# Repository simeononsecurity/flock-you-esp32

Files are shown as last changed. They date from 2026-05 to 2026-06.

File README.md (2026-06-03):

# Flock-You: Promiscuous WiFi Edition (`promiscious-dev` branch)

Flock You

**Passive 2.4 GHz promiscuous-mode detector for Flock Safety surveillance infrastructure. Runs standalone or feeds the Flask dashboard over USB for live GPS-tagged wardriving.**

> **Dev note:** This is the `promiscious-dev` branch — adds the
> DeFlockJoplin wildcard-probe tightening and a 31st OUI on top of the
> `promiscious` baseline. See "Further research" below.

---

## Credit

All WiFi promiscuous detection research — the **30-OUI target list**, the **promiscuous-mode strategy**, and the **addr1-receiver detection technique** — is the work of **ØяĐöØцяöЪöяцฐ / @NitekryDPaul**. The firmware here is a mod of his original firmware with added SPIFFS persistence and Flask-dashboard integration. Full research writeup: [`datasets/NitekryDPaul_wifi_ouis.md`](datasets/NitekryDPaul_wifi_ouis.md).

Additional research credit to **Michael / DeFlockJoplin** for the **wildcard-probe-request signature** and the 31st OUI (`82:6b:f2`). Field-tested to 11/12 cameras caught with only 2 false positives in Joplin. Source: [DeflockJoplin/flock-you](https://github.com/DeflockJoplin/flock-you).

---

## What this branch does

Turns a Seeed XIAO ESP32-S3 into a passive WiFi receiver that watches 2.4 GHz management and data frames for Flock Safety MAC OUIs. No AP, no transmit — the radio stays dedicated to sniffing while the device hops channels 1 / 6 / 11 at 350 ms dwell.

Every detection is:

- beeped (piezo on GPIO3) and flashed (onboard LED on GPIO21)
- written to on-device SPIFFS in an atomic CRC-envelope format, surviving power loss
- emitted as one JSON line over USB CDC in the schema `api/flockyou.py` expects, so the Flask dashboard auto-ingests it with GPS temporal matching

The device works standalone (no USB host needed) and plugged in (live dashboard) without any mode switch.

---

## Why promiscuous mode, and why `addr1`

Most WiFi sniffers only check the transmitter address (`addr2`). Flock infrastructure spends most of its duty cycle **asleep** — it wakes briefly in bursts, uploads, then sleeps again. During the silence it may never transmit a single frame in your capture window.

But it may still appear on the air as the **destination** (`addr1`) of probe responses or data frames from nearby APs.

Checking `addr1` in addition to `addr2` picks those silent stations up. It requires two guards to avoid false positives:

- `addr1` is broadcast (`ff:ff:ff:ff:ff:ff`) in beacons and broadcasts — **multicast filter**
- Modern devices use randomised (locally-administered) MACs that can't be fingerprinted by OUI — **randomised-MAC filter** on byte 0 bit 1

Both are applied before the OUI match. This whole approach, including the 30-OUI list, is **@NitekryDPaul's research**.

---

## Further research — the wildcard-probe signature (DeFlockJoplin)

Michael / DeFlockJoplin used the OUI + addr1/addr2/addr3 work above as a starting point and characterised what Flock cameras actually do on the air. His finding:

> The cameras are hopping channels and sending out a wildcard WiFi probe request on every channel. This specific type of request combined with OUI matching has created what seems to be a fairly unique signature.

His drive-test in Joplin caught **11 of 12 cameras** with only **2 false positives**. The 12th camera was doing the same wildcard-probe behaviour but with an OUI (`82:6b:f2`) that wasn't in @NitekryDPaul's original 30 — it's now the 31st entry in our list, credited to him.

The tightened signature that's active on this branch:

1. Frame is 802.11 Management, type=0 subtype=4 (**Probe Request**)
2. SSID Information Element (tag 0) is present with **length 0** (wildcard)
3. `addr2` (transmitter) matches the known-OUI list

When all three hit, we emit `detection_method: wifi_wildcard_probe` — the high-precision class. Non-probe frames from the same OUIs still emit `wifi_oui_addr2`, and the `addr1` receiver-side sleeper-catch still runs independently.

His proof-of-concept firmware (different enough we're not just pulling it in wholesale, but the core idea carried over cleanly): [DeflockJoplin/flock-you](https://github.com/DeflockJoplin/flock-you). The wildcard-probe analysis is his; we ported the detection into this firmware and kept our SPIFFS persistence, Flask JSON emission, and audio/LED feedback on top.

---

## Detection pipeline

```
  [2.4GHz air]
       │
       ▼
  wifiSniffer()                 ← IRAM promiscuous callback (WiFi task)
       │                          fast match only, no Serial / no malloc
       ▼
  alertQueue[32]                ← lock-free ring buffer (ISR-safe mux)
       │
       ▼
  drainAlertQueue()             ← loop() context, per-iteration drain
       │
       ├─► fyAddDetection()           ← always, every hit
       │        │
       │        ▼
       │   fyDet[200]                 ← unique-by-MAC on-device table
       │        │
       │        ▼
       │   autosaveTick()             ← every 60s when dirty
       │        │
       │        ▼
       │   fySaveSession()            ← atomic CRC-envelope write to SPIFFS
       │
       ├─► shouldSuppressDuplicate()  ← 5s per-MAC serial-emit rate limit
       │
       └─► emitDetectionJSON()        ← USB CDC line for Flask
            buzzerBeep() + ledFlash()
```

The split between callback and loop is deliberate: the WiFi task has hard real-time constraints and cannot call `Serial.print` or `malloc` safely. The callback writes only to the lock-free ring buffer; `loop()` does all the heavy work.

---

## OUI target list (@NitekryDPaul research)

All lowercase, colon-separated. 31 Flock Safety infrastructure prefixes:

```
70:c9:4e   3c:91:80   d8:f3:bc   80:30:49   b8:35:32
14:5a:fc   74:4c:a1   08:3a:88   9c:2f:9d   c0:35:32
94:08:53   e4:aa:ea   f4:6a:dd   f8:a2:d6   24:b2:b9
00:f4:8d   d0:39:57   e8:d0:fc   e0:4f:43   b8:1e:a4
70:08:94   58:8e:81   ec:1b:bd   3c:71:bf   58:00:e3
90:35:ea   5c:93:a2   64:6e:69   48:27:ea   a4:cf:12
82:6b:f2   ← contributed by Michael / DeFlockJoplin
```

Pre-compiled into a byte table in `setup()` so the matcher stays entirely in IRAM with no flash-resident lookups during callback execution.

Full dataset and methodology: [`datasets/NitekryDPaul_wifi_ouis.md`](datasets/NitekryDPaul_wifi_ouis.md).

---

## SPIFFS wire format

On-flash layout, atomic and crash-safe:

```
Line 1: {"v":1,"count":N,"bytes":B,"crc":"0xXXXXXXXX"}
Line 2: [{"mac":"...","method":"...","rssi":...,...},...]
```

Save procedure:

1. Compute CRC32 + byte count over the serialised payload
2. Write envelope header + payload to `/session.tmp`
3. Re-read and re-validate `/session.tmp` (CRC check)
4. Remove `/session.json`
5. Atomic rename `/session.tmp` → `/session.json` (copy+delete fallback)

Boot recovery:

1. If `/session.json` validates, promote it to `/prev_session.json`
2. Otherwise try `/session.tmp` (interrupted save)
3. Delete both working files, start with an empty live table
4. `/prev_session.json` stays around for inspection

CRC32 uses the standard `0xEDB88320` polynomial so the same file can be verified on a host with any off-the-shelf CRC tool.

---

## Flask dashboard integration

The firmware emits one JSON line per detection in the same schema the BLE detector uses, so `api/flockyou.py` picks it up with zero changes:

```json
{"event":"detection","detection_method":"wifi_oui_addr2","protocol":"wifi_2_4ghz","mac_address":"aa:bb:cc:dd:ee:ff","oui":"aa:bb:cc","device_name":"","rssi":-62,"channel":6,"frequency":2437,"ssid":""}
```

`detection_method` values:

- `wifi_wildcard_probe` — **Probe Request + wildcard SSID from a known OUI** (the DeFlockJoplin high-precision signature). When this fires, the `addr2` broad alert is suppressed for the same frame to avoid double-counting.
- `wifi_oui_addr2` — transmitter-side OUI match on any non-probe frame
- `wifi_oui_addr1` — **receiver-side OUI match** (the @NitekryDPaul technique)
- `wifi_oui_addr3` — BSSID OUI match (mgmt frames only; disabled by default)
- `wifi_ssid` — SSID keyword match (disabled by default)

### GPS wardriving

GPS is handled Flask-side, since the ESP32 radio is dedicated to sniffing and there's no on-device AP. Two options:

- **USB NMEA puck** plugged into the host running Flask — Flask reads NMEA and timestamps a GPS timeline
- **Flask dashboard open in a phone browser** — browser Geolocation API posts updates to Flask

Flask does a temporal match between detection timestamp and GPS timeline, then exports JSON / CSV / KML for Google Earth.

### Running Flask

```bash
cd api
pip install -r requirements.txt
python flockyou.py
```

Open `http://localhost:5000`, pick your serial port from the UI, detections start showing up live.

---

## Supported Hardware

Five environments are included in `platformio.ini`. Pick the one that matches your board; everything else is automatic.

| Environment | Board | Port type | Speaker / LED | Notes |
|---|---|---|---|---|
| `xiao_esp32s3` | Seeed XIAO ESP32-S3 | `/dev/tty.usbmodem*` | GPIO3 piezo + GPIO21 LED | **Original upstream board** |
| `esp32dev` | Generic ESP32 DevKit | `/dev/tty.usbserial-*` | GPIO25 piezo + GPIO2 LED | Bare dev board |
| `m5atom-echo` | M5Stack Atom Echo | `/dev/tty.usbserial-*` | NeoPixel (G27) + GPIO25 buzzer | Compact with speaker |
| `m5atom-lite` | M5Stack Atom Lite | `/dev/tty.usbserial-*` | NeoPixel (G27), no speaker | Ultra-compact |
| `m5atom-voices3r` | M5Stack Atom VoiceS3R | `/dev/tty.usbmodem*` | ES8311 I²S speaker via M5Unified | ESP32-S3, 8MB PSRAM |

### Pin map — XIAO ESP32-S3 (original)

| Pin | Function |
|-----|---|
| GPIO 3 | Piezo buzzer |
| GPIO 21 | Onboard user LED (active low) |
| GPIO 43 | Serial1 TX mirror (115200 baud) |

### Pin map — Atom VoiceS3R

| Pin | Function |
|-----|---|
| GPIO 41 | User button |
| GPIO 18 | Speaker amp enable (NS4150_CTR, handled by M5Unified) |
| I²S (G45/G0/G48/G4/G3/G17/G11) | ES8311 codec — M5Unified drives this automatically |

Boot sound: **Super Mario Bros. World 1-1 overworld opening riff** (E E _E_ C E G) on VoiceS3R / Atom Echo; first 6 notes of World 1-2 underground on original buzzer boards.

---

## Build and flash

Requires [PlatformIO](https://platformio.org/) (`pip install platformio` or install the VS Code extension).

### Quick start — any board

```bash
# Build for your board (replace <env> with one of the environment names above)
pio run -e <env>

# Build + flash
pio run -e <env> -t upload

# Serial monitor
pio device monitor -e <env>
```

### Board-specific commands

#### Seeed XIAO ESP32-S3 (original upstream board)
```bash
pio run -e xiao_esp32s3 -t upload
pio device monitor -e xiao_esp32s3

# Serial monitor (direct):
screen $(ls /dev/tty.usbmodem* | head -1) 115200
```

#### Generic ESP32 DevKit
```bash
pio run -e esp32dev -t upload
pio device monitor -e esp32dev

# Serial monitor (direct):
screen $(ls /dev/tty.usbserial-* | head -1) 115200
```

#### M5Stack Atom Echo
```bash
pio run -e m5atom-echo -t upload
pio device monitor -e m5atom-echo

# Serial monitor (direct):
screen $(ls /dev/tty.usbserial-* | head -1) 115200
```

#### M5Stack Atom Lite
```bash
pio run -e m5atom-lite -t upload
pio device monitor -e m5atom-lite

# Serial monitor (direct):
screen $(ls /dev/tty.usbserial-* | head -1) 115200
```

#### M5Stack Atom VoiceS3R (ESP32-S3, native USB-CDC)
The VoiceS3R uses native USB — `pio run -t upload` works when the port is free.
If the port is busy (e.g. a serial monitor is open), kill it first:

```bash
# Kill anything holding the CDC port, then flash:
lsof -t /dev/tty.usbmodem* | xargs kill 2>/dev/null; sleep 0.5
pio run -e m5atom-voices3r -t upload

# Or use brew esptool directly (most reliable for ESP32-S3 native USB):
esptool --chip esp32s3 --port /dev/tty.usbmodem101 \
    --before usb-reset --after hard-reset write-flash \
    0x0    .pio/build/m5atom-voices3r/bootloader.bin \
    0x8000 .pio/build/m5atom-voices3r/partitions.bin \
    0xe000 ~/.platformio/packages/framework-arduinoespressif32/tools/partitions/boot_app0.bin \
    0x10000 .pio/build/m5atom-voices3r/firmware.bin

# Serial monitor:
screen /dev/tty.usbmodem101 115200
# (replace 101 with whatever number the port shows — run: ls /dev/tty.usbmodem*)
```

> **Tip:** After flashing the VoiceS3R, unplug and replug the USB cable once to let the firmware re-enumerate the CDC port.

### Testing mode

To alert on **all** WiFi frames (useful for range/hardware testing before deployment), add `-DTESTING_MODE=1` to any env's `build_flags`:

```ini
build_flags =
    ...
    -DTESTING_MODE=1
```

Remove it to return to normal Flock OUI–only detection.

`platformio.ini` and `partitions_4mb.csv` are at the root. The XIAO env uses `partitions.csv` (original upstream layout); all other envs use `partitions_4mb.csv`.

---

## Config cheatsheet (top of `main.cpp`)

| Define | Default | Notes |
|---|---|---|
| `CHANNEL_MODE` | `CHANNEL_MODE_CUSTOM` | `CUSTOM` (1/6/11), `FULL_HOP` (1-11), or `SINGLE` |
| `CHANNEL_DWELL_MS` | 350 | Time on each channel before hop |
| `RSSI_MIN` | -95 | Drop frames weaker than this |
| `ALERT_COOLDOWN_MS` | 5000 | Per-MAC serial-emit rate limit |
| `CHECK_ADDR1` | 1 | The @NitekryDPaul receiver-side technique |
| `CHECK_ADDR3` | 0 | BSSID fallback (mgmt frames only) |
| `ENABLE_SSID_MATCH` | 0 | Substring match against `target_ssid_keywords[]` |
| `PROCESS_MGMT_FRAMES` | 1 | Beacons, probe req/resp, etc. |
| `PROCESS_DATA_FRAMES` | 1 | Data frames (where addr1 catch shines) |
| `MAX_DETECTIONS` | 200 | On-device table cap |
| `AUTOSAVE_INTERVAL_MS` | 60000 | SPIFFS save cadence |
| `LED_PIN` | 21 | Onboard user LED |
| `BUZZER_PIN` | 3 | Piezo |

---

## Standalone vs connected

**Without USB:** device boots, plays the SMB 1-2 intro, starts scanning, stores every unique detection to SPIFFS, flashes the onboard LED on each hit. Plug in later — the prior session is sitting in `/prev_session.json`.

**With USB + Flask running:** same thing, plus every detection streams live to the dashboard as a JSON line. Flask adds GPS (if configured) and deduplicates across MAC, building the wardriving map as you move.

Both modes work simultaneously — the SPIFFS write path doesn't care if a host is listening.

---

## BLE companion firmware

The BLE-only sibling of this firmware lives on the [`main` branch](https://github.com/colonelpanichacks/flock-you/tree/main). It detects Flock and Raven gear via BLE advertisements (OUI prefix, device name, manufacturer ID `0x09C8`, Raven service UUIDs), runs its own WiFi AP with a phone-facing dashboard at `192.168.4.1`, and emits the same Flask JSON schema. Flash both on separate boards for overlapping BLE + WiFi coverage feeding one Flask dashboard.

---

## Acknowledgments

- **ØяĐöØцяöЪöяцฐ (@NitekryDPaul)** — **WiFi promiscuous detection research**: the 30-OUI Flock Safety target list and the addr1-receiver detection technique that are the baseline of this firmware. The code here is a mod of his original work.
- **Michael / DeFlockJoplin** ([DeflockJoplin/flock-you](https://github.com/DeflockJoplin/flock-you), [deflockjoplin.today](https://deflockjoplin.today)) — **wildcard-probe-request signature** + the 31st OUI (`82:6b:f2`). Drive-tested in Joplin to 11/12 cameras caught with only 2 false positives.
- **Will Greenberg** ([@wgreenberg](https://github.com/wgreenberg)) — BLE manufacturer company ID detection (`0x09C8` XUNTONG) sourced from his [flock-you](https://github.com/wgreenberg/flock-you) fork (used by the BLE companion on `main`)
- **[DeFlock](https://deflock.me)** ([FoggedLens/deflock](https://github.com/FoggedLens/deflock)) — crowdsourced ALPR location data and detection methodologies. Datasets included in `datasets/`
- **[GainSec](https://github.com/GainSec)** — Raven BLE service UUID dataset (`raven_configurations.json`) used by the BLE companion

---

## OUI-SPY Firmware Ecosystem

Flock-You is part of the OUI-SPY firmware family:

| Firmware | Description | Board |
|---|---|---|
| **[OUI-SPY Unified](https://github.com/colonelpanichacks/oui-spy-unified-blue)** | Multi-mode BLE + WiFi detector | ESP32-S3 / ESP32-C5 |
| **[OUI-SPY Detector](https://github.com/colonelpanichacks/ouispy-detector)** | Targeted BLE scanner with OUI filtering | ESP32-S3 |
| **[OUI-SPY Foxhunter](https://github.com/colonelpanichacks/ouispy-foxhunter)** | RSSI-based proximity tracker | ESP32-S3 |
| **[Flock You](https://github.com/colonelpanichacks/flock-you)** | Flock Safety / Raven surveillance detection (this project) | ESP32-S3 |
| **[Sky-Spy](https://github.com/colonelpanichacks/Sky-Spy)** | Drone Remote ID detection | ESP32-S3 / ESP32-C5 |
| **[Remote-ID-Spoofer](https://github.com/colonelpanichacks/Remote-ID-Spoofer)** | WiFi Remote ID spoofer & simulator with swarm mode | ESP32-S3 |
| **[OUI-SPY UniPwn](https://github.com/colonelpanichacks/Oui-Spy-UniPwn)** | Unitree robot exploitation system | ESP32-S3 |

---

## Author

**colonelpanichacks**

**Oui-Spy devices available at [colonelpanic.tech](https://colonelpanic.tech)**

---

## Disclaimer

Passive reception of publicly-broadcast 802.11 frames for security research, privacy auditing, and education. The device does not transmit and does not authenticate to any network. Detecting the presence of surveillance hardware in public spaces is legal in most jurisdictions; always comply with local laws regarding wireless reception.

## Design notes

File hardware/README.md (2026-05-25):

# Hardware Directory

This directory contains the 3D printable case design and rendering tools.

## 📁 Contents

```
hardware/
├── openscad/
│   └── flock-you-case.scad       ← Parametric CAD source
├── renders/                       ← Generated product images (create with script)
├── render_models.sh               ← Automated rendering script
├── RENDERING_GUIDE.md             ← Complete rendering documentation
└── README.md                      ← This file
```

---

## 🚀 Quick Start

### To Generate Product Images:

**1. Install OpenSCAD:**
```bash
# macOS
brew install openscad

# Linux
sudo apt-get install openscad
```

**2. Run Rendering Script:**
```bash
cd hardware
./render_models.sh
```

This creates professional renders in `renders/` folder:
- `case-base-iso.png` - Base isometric view
- `case-base-top.png` - Base top view  
- `case-lid-iso.png` - Lid isometric view
- `led-pipe.png` - Light pipe detail
- `assembly-exploded.png` - Full assembly exploded view

**3. Use in Documentation:**
Add the generated images to your README, product pages, and build guides.

---

## 📐 Case Specifications

### Dimensions
- **External:** 70mm × 50mm × 25mm
- **Weight:** ~25g (PLA)
- **Print time:** 2-3 hours

### Features
- ✅ Snap-fit lid (no screws)
- ✅ LED light pipe for GPIO 2
- ✅ USB strain relief
- ✅ Ventilation slots
- ✅ Breadboard mounting posts
- ✅ Car dashboard mounting holes

### Fits
- ESP32 DevKit 30-pin
- 170-point mini breadboard
- KY-006 passive buzzer module
- USB cable with strain relief

---

## 🔧 Customizing the Design

### Edit in OpenSCAD GUI

1. Open `openscad/flock-you-case.scad` in OpenSCAD
2. Modify parameters at top of file:
   ```openscad
   case_length = 70;  // Change dimensions
   case_width = 50;
   case_height = 25;
   ```
3. Press **F5** to preview changes
4. Press **F6** to render final model
5. Export STL: File → Export → Export as STL

### Common Customizations

**Make it bigger/smaller:**
```openscad
case_length = 80;  // 10mm longer
case_width = 55;   // 5mm wider
```

**Add ventilation:**
```openscad
vent_slot_w = 2.0;        // Wider slots
vent_slot_spacing = 3;     // More slots
```

**Different LED position:**
```openscad
// In case_lid() module, change light pipe position
translate([30, 25, -lip_h - 1])  // Move to corner
    cylinder(d=led_pipe_d + tol, h=lid_thick + lip_h + 2);
```

---

## 📦 Printing Instructions

### Recommended Settings
- **Material:** PLA, PETG, or ABS
- **Layer Height:** 0.2mm
- **Infill:** 20%
- **Supports:** None needed
- **Print Time:** 2-3 hours total
- **Cost:** $0.50-0.75 in filament

### Print Order
1. Print **base first** (~2 hours)
2. Test fit with components
3. Print **lid** (~45 min)
4. Print **light pipe** in clear filament (~5 min)

---

## 🎨 Render Examples

Once you run `./render_models.sh`, you'll get:

### Case Base (Isometric View)
Shows internal posts, ventilation slots, USB cutout, and snap-fit tabs.

### Case Lid (Isometric View)  
Shows retaining lip, LED light pipe hole, and snap-fit slots.

### LED Light Pipe
Detail view of the custom light guide for GPIO 2 LED.

### Exploded Assembly
Full assembly view showing how parts fit together.

---

## 📸 For Publishers

If you're publishing this project, generate renders by:

1. Installing OpenSCAD (free, open-source)
2. Running `./render_models.sh`
3. Adding images to:
   - Main README (hero shot)
   - Build guides (step-by-step)
   - Product pages (multiple angles)
   - Social media (eye-catching renders)

**Tip:** Use "Tomorrow Night" color scheme for professional dark backgrounds.

---

## 🎓 Learning Resources

- **Full guide:** See `RENDERING_GUIDE.md` for complete documentation
- **OpenSCAD manual:** [openscad.org/documentation](https://openscad.org/documentation.html)
- **Video tutorials:** Search "OpenSCAD rendering" on YouTube

---

## ✅ Checklist for Publication

- [ ] OpenSCAD installed
- [ ] Renders generated (`./render_models.sh`)
- [ ] STL files exported (if distributing printable files)
- [ ] Images added to main README
- [ ] Case design credited in documentation
- [ ] Print settings verified with test print

---

## 🤝 Contributing

Designed a better case? Created a variant?

1. Fork the repository
2. Modify `flock-you-case.scad`
3. Generate renders of your design
4. Submit pull request with photos

**License:** Creative Commons CC-BY-SA 4.0  
Share and remix freely, credit original designers.

---

## 📝 Notes

**Render script not working?**
- Check that OpenSCAD is installed: `openscad --version`
- Verify script is executable: `chmod +x render_models.sh`
- See `RENDERING_GUIDE.md` for troubleshooting

**Need different angles?**
- Edit camera parameters in `render_models.sh`
- Or use OpenSCAD GUI: View → Cameras → Choose angle
- See rendering guide for camera parameter details

**Want to sell printed cases?**
That's explicitly allowed under CC-BY-SA 4.0!
- Print and sell commercially
- Must credit original design
- Share derivative designs under same license

---

## 🎉 Ready to Build!

You now have:
- ✅ Parametric CAD source (customizable)
- ✅ Rendering tools (professional images)
- ✅ Complete documentation
- ✅ Print-ready design

**Next step:** Install OpenSCAD, run `./render_models.sh`, and generate your product images!

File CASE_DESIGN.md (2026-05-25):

# 3D Printable Case Design - Flock-You ESP32

## 📐 Case Specifications

This case is designed to hold a complete Flock-You detector with breadboard assembly.

### Fits These Components
- ESP32 DevKit 30-pin (48mm × 28mm × 12mm)
- 170-point mini breadboard (45mm × 35mm × 9mm)
- KY-006 passive buzzer module (19mm × 15mm)
- USB Micro cable (with strain relief)
- Jumper wires

### Dimensions
- **External:** 70mm (L) × 50mm (W) × 25mm (H)
- **Wall thickness:** 2mm
- **Weight:** ~25g (PLA)
- **Print time:** 2-3 hours (0.2mm layer height)

### Features
✅ Snap-fit lid (no screws needed)  
✅ USB cable strain relief  
✅ LED light pipe for GPIO 2  
✅ Ventilation slots  
✅ Breadboard mounting posts  
✅ Car dashboard mounting holes  
✅ Optional velcro mounting surface  
✅ Compact,

 pocketable design  

---

## 🖨️ Printing Instructions

### Recommended Settings

| Setting | Value | Notes |
|---|---|---|
| **Material** | PLA, PETG, or ABS | PLA easiest, PETG for heat resistance |
| **Layer Height** | 0.2mm | 0.15mm for smoother finish |
| **Infill** | 20% | Gyroid or Grid pattern |
| **Wall Line Count** | 3 | Strong walls |
| **Top/Bottom Layers** | 4 | Solid top/bottom |
| **Print Speed** | 50mm/s | Slower for better quality |
| **Support** | No | Designed to print without |
| **Bed Adhesion** | Brim | Helps with warping |
| **Rafts** | No | Not needed |

### Color Recommendations
- **Base:** Black or gray (looks professional)
- **Lid:** Clear/translucent (see LED through light pipe)
- **Accent parts:** Red or yellow (for button/indicator)

### Print Time & Cost
- **Base:** 1.5-2 hours, ~15g filament ($0.30-0.50)
- **Lid:** 30-45 minutes, ~8g filament ($0.15-0.25)
- **Total:** 2-3 hours, ~25g filament ($0.50-0.75)

---

## 📦 Files Included

All STL files are in `/firmware/hardware/stl/` folder:

1. **flock-you-case-base.stl** - Main enclosure bottom
2. **flock-you-case-lid.stl** - Snap-on top cover
3. **flock-you-led-pipe.stl** - Light guide for onboard LED
4. **flock-you-mount-bracket.stl** - Optional car mount (separate)

### Optional Parts
5. **spacer-3mm.stl** - Raises lid if components too tall
6. **usb-adapter-90deg.stl** - Right-angle USB adapter holder

---

## 🔧 Assembly Instructions

### What You Need
- Printed case base & lid
- LED light pipe (printed clear)  
- Assembled ESP32 + breadboard + buzzer
- (Optional) 2× M3×8mm screws for mounting bracket

### Step-by-Step

**Step 1: Install LED Light Pipe**
1. Locate LED light pipe hole in case lid (small circular hole)
2. Insert printed light pipe from inside
3. Push gently until it clicks flush
4. The pipe should protrude slightly inside to touch GPIO 2 LED

**Step 2: Mount Breadboard**
1. Identify 4 mounting posts inside case base
2. Peel adhesive backing off breadboard (if present)
3. Align breadboard over mounting posts
4. Press down firmly to seat breadboard
5. (Optional) Add small piece of double-sided tape for extra grip

**Step 3: Route USB Cable**
1. Thread USB cable through strain relief channel
2. Plug into ESP32
3. Cable should exit at back of case cleanly
4. Gentle pressure on strain relief locks cable in place

**Step 4: Close the Lid**
1. Align lid tabs with case base slots (4 corners)
2. Gently push down lid starting from one end
3. Work around perimeter, pressing each tab
4. Lid should "snap" into place securely
5. To open: Insert fingernail in slot at front, flex and lift

**Step 5: Test Fit**
1. Plug in USB to power on
2. LED should be visible through light pipe
3. Buzzer sound should be clear (not muffled)
4. All buttons accessible (if added)

### Common Issues & Fixes

**Lid won't snap:**
- Tabs too thick - sand them down slightly
- Posts interfering - trim with flush cutters
- Print elephants foot - scale lid X/Y by 101%

**Buzzer sounds muffled:**
- Add ventilation slots (see OpenSCAD mod below)
- Orient buzzer facing down toward slots
- Add acoustic port (drill 8mm hole)

**USB cable loose:**
- Add small zip tie through strain relief
- Print thicker strain relief variant
- Use hot glue (remove

able) as temporary fix

---

## 🖥️ OpenSCAD Source Code

The case is parametric - easily modify dimensions!

### Download & Edit

1. Install [OpenSCAD](https://openscad.org/) (free, open-source)
2. Open `/firmware/hardware/openscad/flock-you-case.scad`
3. Modify parameters at top of file
4. Press F5 to preview, F6 to render
5. Export STL: File → Export → Export as STL

### Quick Customization Parameters

```openscad
// === USER PARAMETERS ===

// Case dimensions (mm)
case_length = 70;
case_width = 50;
case_height = 25;
wall_thickness = 2;

// Component fitment
esp32_length = 48;
esp32_width = 28;
breadboard_length = 45;
breadboard_width = 35;

// Features
led_pipe_diameter = 3;  // Light pipe for GPIO 2 LED
usb_cutout_width = 12;
usb_strain_relief = true;
ventilation_slots = true;
mounting_holes = true;

// Tolerances (increase if too tight)
snap_fit_tolerance = 0.3;
component_clearance = 1.0;
```

### Full OpenSCAD Code

Save as `flock-you-case.scad`:

```openscad
// ============================================
// Flock-You ESP32 Case - Parametric Design
// ============================================
// Licensed under Creative Commons CC-BY-SA 4.0
// Designed for ESP32 DevKit + Breadboard

// === PARAMETERS ===

// Case dimensions
case_length = 70;
case_width = 50;
case_height = 25;
wall = 2;
corner_r = 3;

// Component dimensions
esp32_l = 48;
esp32_w = 28;
esp32_h = 12;
breadboard_l = 45;
breadboard_w = 35;
breadboard_h = 9;

// Features
led_pipe_d = 3;
led_pipe_h = 8;
usb_w = 12;
usb_h = 8;
vent_slot_w = 1.5;
vent_slot_spacing = 4;

// Tolerances
tol = 0.3;
clearance = 1.0;

// === MODULES ===

module case_base() {
    difference() {
        // Main body
        minkowski() {
            cube([case_length - 2*corner_r, 
                  case_width - 2*corner_r, 
                  case_height/2]);
            cylinder(r=corner_r, h=case_height/2, $fn=32);
        }
        
        // Hollow interior
        translate([wall, wall, wall])
            cube([case_length - 2*wall, 
                  case_width - 2*wall,
                  case_height]);
        
        // USB cutout (back)
        translate([case_length - wall - 5, 
                   (case_width - usb_w)/2, 
                   wall + 2])
            cube([10, usb_w, usb_h]);
        
        // USB strain relief channel
        translate([case_length - 15, 
                   (case_width - usb_w + 2)/2, 
                   wall])
            cube([15, usb_w - 2, 3]);
        
        // Ventilation slots (bottom)
        for (i = [0:5]) {
            translate([10 + i * vent_slot_spacing, 
                       5, 
                       -1])
                cube([vent_slot_w, case_width - 10, wall + 2]);
        }
        
        // Mounting holes (corners, optional)
        for (x = [5, case_length - 5])
            for (y = [5, case_width - 5])
                translate([x, y, -1])
                    cylinder(d=3.2, h=wall + 2, $fn=16);
    }
    
    // Breadboard mounting posts
    post_h = 3;
    post_d = 3;
    posts_offset_x = (case_length - breadboard_l) / 2;
    posts_offset_y = (case_width - breadboard_w) / 2;
    
    for (x = [posts_offset_x, posts_offset_x + breadboard_l - post_d])
        for (y = [posts_offset_y, posts_offset_y + breadboard_w - post_d])
            translate([x, y, wall])
                cylinder(d=post_d, h=post_h, $fn=16);
    
    // Snap-fit tabs (lid retention)
    tab_w = 4;
    tab_h = 2;
    tab_d = 1.5;
    
    for (x = [10, case_length - 10 - tab_w])
        for (y = [0, case_width - tab_d]) {
            translate([x, y, case_height - tab_h])
                cube([tab_w, tab_d, tab_h]);
        }
}

module case_lid() {
    lid_thick = 2;
    lip_h = 3;
    lip_inset = wall - tol;
    
    difference() {
        union() {
            // Top surface
            minkowski() {
                cube([case_length - 2*corner_r, 
                      case_width - 2*corner_r, 
                      lid_thick/2]);
                cylinder(r=corner_r, h=lid_thick/2, $fn=32);
            }
            
            // Retaining lip
            translate([lip_inset, lip_inset, -lip_h])
                cube([case_length - 2*lip_inset, 
                      case_width - 2*lip_inset,
                      lip_h]);
        }
        
        // LED light pipe hole
        translate([case_length/2, case_width/2, -lip_h - 1])
            cylinder(d=led_pipe_d + tol, h=lid_thick + lip_h + 2, $fn=16);
        
        // Snap-fit tab slots
        tab_w = 4 + 2*tol;
        tab_h = 2 + tol;
        tab_d = 1.5 + tol;
        
        for (x = [10 - tol, case_length - 10 - tab_w + tol])
            for (y = [-1, case_width - tab_d + 1]) {
                translate([x, y, -lip_h - 1])
                    cube([tab_w, tab_d, lip_h + tab_h + 1]);
            }
        
        // Label recess (optional)
        translate([case_length/2 - 20, case_width/2 - 5, lid_thick - 0.5])
            linear_extrude(0.6)
                text("FLOCK-YOU", size=4, halign="center", font="Liberation Sans:style=Bold");
    }
}

module led_light_pipe() {
    // Clear filament light guide
    pipe_l = led_pipe_h;
    pipe_d = led_pipe_d - 0.2;  // Snug fit
    
    cylinder(d1=pipe_d, d2=pipe_d - 0.5, h=pipe_l, $fn=32);
    
    // Retention ridge
    translate([0, 0, pipe_l - 1])
        cylinder(d=pipe_d + 0.5, h=0.5, $fn=32);
}

module mounting_bracket() {
    // Car dashboard / velcro mount
    bracket_l = case_length + 10;
    bracket_w = 30;
    bracket_thick = 3;
    
    difference() {
        // Base plate
        minkowski() {
            cube([bracket_l - 2*corner_r, 
                  bracket_w - 2*corner_r, 
                  bracket_thick/2]);
           cylinder(r=corner_r, h=bracket_thick/2, $fn=32);
        }
        
        // Screw holes for case attachment
        for (x = [5, case_length + 5])
            for (y = [bracket_w/2])
                translate([x, y, -1])
                    cylinder(d=3.2, h=bracket_thick + 2, $fn=16);
        
        // Velcro adhesive area (smooth)
        translate([bracket_l/2 - 25, 5, bracket_thick - 0.5])
            cube([50, bracket_w - 10, 1]);
    }
}

// === RENDER SELECTION ===

// Uncomment the part you want to generate:

case_base();

//translate([0, case_width + 10, 0])  // Offset for printing both
//    case_lid();

//translate([case_length/2, case_width/2, 0])
//    led_light_pipe();

//translate([0, case_width + 40, 0])
//    mounting_bracket();
```

---

## 🎨 Customization Ideas

### 1. Add Text Label
```openscad
linear_extrude(0.6)
    text("DEFLOCK", size=6, font="Arial:style=Bold");
```

### 2. Bigger Ventilation
```openscad
// Replace ventilation_slots section with:
for (i = [0:8]) {
    translate([8 + i * 3, 3, -1])
        cube([2, case_width - 6, wall + 2]);
}
```

### 3. Battery Compartment
```openscad
// Add to case_base():
translate([5, 5, wall])
    cube([20, case_width - 10, 15]);  // 18650 holder space
```

### 4. External Antenna Port
```openscad
// For ESP32-WROOM-32U with U.FL connector:
translate([10, case_width - wall - 1, case_height/2])
    rotate([90, 0, 0])
        cylinder(d=6.5, h=wall + 2, $fn=16);  // SMA bulkhead mount
```

### 5. Lanyard Hole
```openscad
translate([case_length - 5, case_width/2, case_height - 5])
    rotate([0, 90, 0])
        cylinder(d=4, h=wall + 2, $fn=16);
```

---

## 📏 Dimensions Reference

### ESP32 DevKit 30-pin Footprint
```
            48mm
    ┌──────────────────┐
    │    ESP32-WROOM   │
    │                  │ 28mm
    │  USB ████████    │
    └──────────────────┘
    
Pin spacing: 2.54mm (0.1")
Board thickness: 1.6mm
Height with components: ~12mm
```

### KY-006 Buzzer Module
```
       19mm
    ┌────────┐
    │  )))   │ 15mm
    │  )))   │
    └─●─●─●──┘
     S + GND
```

### 170-Point Breadboard
```
         45mm
    ┌──────────────┐
    │ ● ● ● ● ● ●  │
    │ ● ● ● ● ● ●  │ 35mm
    │ ● ● ● ● ● ●  │
    └──────────────┘
    
Mounting holes: 41mm × 31mm spacing
```

---

## 🛠️ Post-Processing

### Smoothing & Finishing

**Method 1: Sanding**
1. Wet-sand with 220 grit → 400 grit → 800 grit
2. Wipe clean with damp cloth
3. Optional: Clear coat spray (matte or gloss)

**Method 2: Vapor Smoothing** (ABS only)
1. Suspend print in sealed container
2. Add small amount of acetone to bottom
3. Leave 30 seconds - 2 minutes
4. Remove and let cure 24 hours
5. ⚠️ Ventilate well, acetone fumes hazardous

**Method 3: Filler + Paint**
1. Apply spray filler primer
2. Sand smooth with 400 grit
3. Spray paint desired color
4. Clear coat for protection

### Light Pipe Optimization

For best LED visibility:
1. Print light pipe in **clear or natural PLA**
2. Sand inside surface lightly (diffuses light)
3. Polish outside with progressively finer sandpaper (up to 3000 grit)
4. Optional: Apply clear epoxy resin for glass-like finish

---

## 📖 Design Philosophy

### Why This Design?

**✅ Printable Without Supports**
- All overhangs < 45°
- No bridging over large gaps
- Snap-fits eliminate screws

**✅ Accessible Components**
- Easy to open for firmware updates
- USB port accessible
- LED visible
- Buzzer unobstructed

**✅ Vehicular Use**
- Mounting options for dashboard
- Strain relief prevents cable damage
- Compact size fits cupholder
- Ventilated for heat dissipation

**✅ Beginner-Friendly**
- Simple two-part design
- No complex assembly
- Tolerances forgiving (±0.3mm works)
- Remixable OpenSCAD source

---

## 🔄 Remix & Share

### License: Creative Commons CC-BY-SA 4.0

**You are free to:**
- ✅ Share — copy and redistribute
- ✅ Adapt — remix, transform, build upon
- ✅ Commercial use - sell printed cases

**Under these terms:**
- 📝 Attribution — Credit original designer
- 🔄 ShareAlike — Same license on derivatives
- 🚫 No additional restrictions

### Share Your Remix!
- Upload to Thingiverse, Printables, or Thangs
- Tag with #flockyou #esp32 #surveillance
- Link back to original design
- Post photos of your build!

---

## 🎓 Learning Resources

### New to 3D Printing?
- **Basics:** [All3DP Beginner's Guide](https://all3dp.com/)
- **Software:** [PrusaSlicer Tutorial](https://help.prusa3d.com/)
- **Troubleshooting:** [Simplify3D Print Quality Guide](https://www.simplify3d.com/support/print-quality-troubleshooting/)

### OpenSCAD Resources
- **Official Docs:** [openscad.org/documentation](https://openscad.org/documentation.html)
- **Tutorial:** [OpenSCAD for Beginners](https://en.wikibooks.org/wiki/OpenSCAD_User_Manual)
- **Gallery:** Thousands of parametric designs to learn from

### Want to Modify?
1. Start with provided parameters (easy)
2. Add simple features (holes, text)
3. Learn modules (reusable components)
4. Advanced: Create fully parametric designs

---

## ✅ Print Checklist

- [ ] STL files downloaded
- [ ] Slicer configured (settings above)
- [ ] Printer bed leveled
- [ ] Filament loaded (20g+ needed)
- [ ] Print started (base first)
- [ ] Base printed successfully (~2 hours)
- [ ] Lid printed (~45 minutes)
- [ ] Light pipe printed (clear filament, ~5 min)
- [ ] Parts cleaned (remove brim/supports if any)
- [ ] Test fit (lid snaps onto base)
- [ ] Ready to assemble!

---

## 🎉 You're Done!

You now have a **professional-looking enclosure** for your Flock-You detector!

**Case cost:** $0.50-0.75 in filament  
**Print time:** 2-3 hours  
**Assembly time:** 5 minutes  
**Result:** Clean, portable, car-ready detector  

**Optional add-ons:**
- Vinyl sticker with warning/branding
- Velcro strips for quick mounting
- Carabiner clip for lanyard attachment
- External antenna mod for extended range

Happy printing! 🖨️

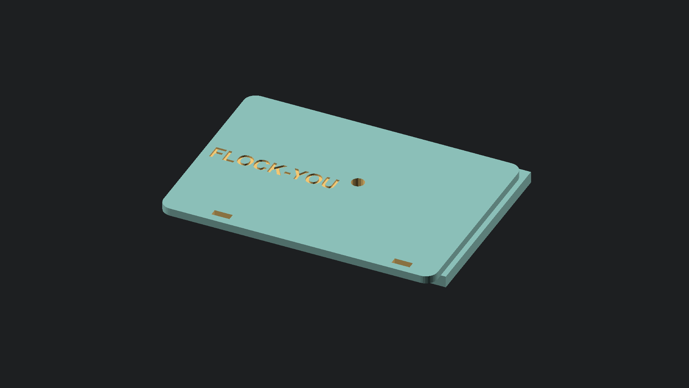
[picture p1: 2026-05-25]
hardware/renders/case-lid-iso.png

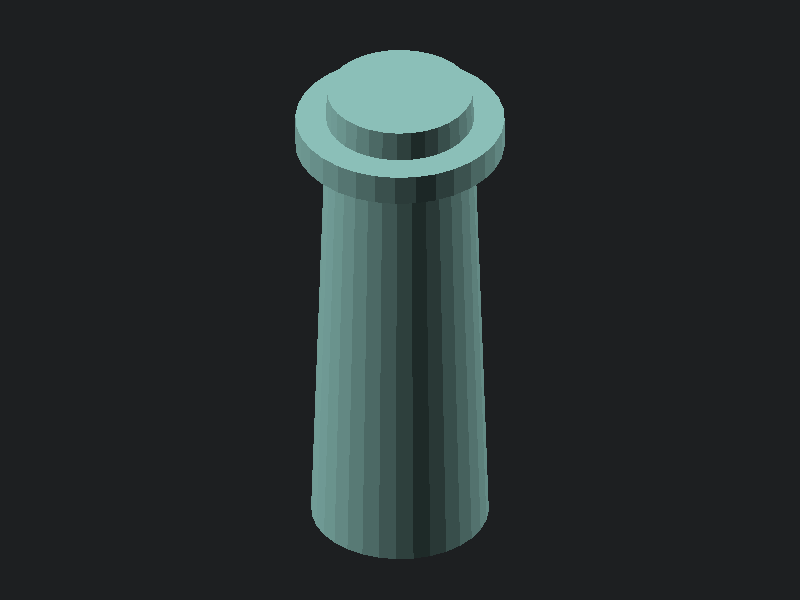
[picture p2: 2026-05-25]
hardware/renders/led-pipe.png

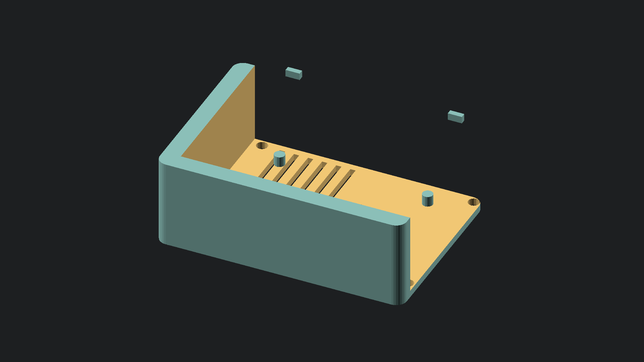
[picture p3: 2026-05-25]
hardware/renders/case-base-iso.png

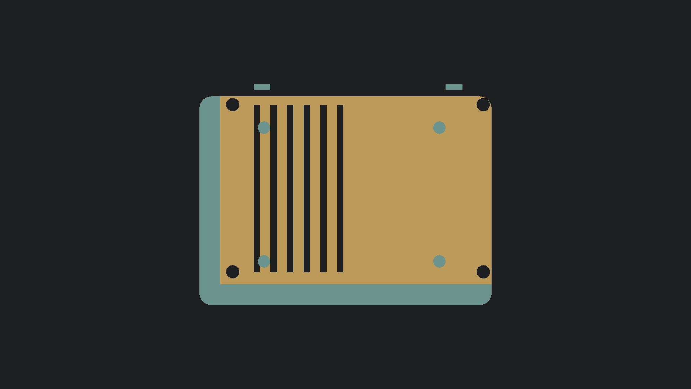
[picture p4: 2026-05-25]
hardware/renders/case-base-top.png

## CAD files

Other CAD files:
hardware/openscad/flock-you-case.scad

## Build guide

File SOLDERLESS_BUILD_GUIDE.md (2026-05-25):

# Solderless Build Guide - Flock-You ESP32

## 🎯 Goal: Build Without Soldering

This guide shows you how to assemble a Flock-You detector using **zero soldering** - perfect for beginners or quick prototypes.

---

## 🛒 Shopping List (Solderless Components)

### Option 1: Breadboard Build ($8-10)
| Item | Quantity | Price | Where to Buy |
|---|---|---|---|
| ESP32 DevKit (30-pin) | 1 | $5-6 | Amazon, AliExpress |
| 400-point Breadboard | 1 | $2 | Amazon, AliExpress |
| Passive Piezo Buzzer Module | 1 | $1-2 | Amazon, AliExpress |
| Male-to-Male Jumper Wires | 3 | <$1 | Amazon, AliExpress |
| USB Micro Cable | 1 | $1 | Amazon, local stores |

**Total: $9-11**

### Option 2: Grove System Build ($12-15)
| Item | Quantity | Price | Where to Buy |
|---|---|---|---|
| ESP32 DevKit with Grove Base | 1 | $8-10 | Seeed Studio, Amazon |
| Grove Buzzer Module | 1 | $3-4 | Seeed Studio, Amazon |
| Grove Cable (4-pin) | 1 | $1 | Usually included |
| USB Micro Cable | 1 | $1 | Amazon, local stores |

**Total: $13-16**

### Option 3: Qwiic/STEMMA System Build ($15-18)
| Item | Quantity | Price | Where to Buy |
|---|---|---|---|
| ESP32 DevKit (any) | 1 | $5-6 | Amazon, AliExpress |
| Qwiic/STEMMA Buzzer Breakout | 1 | $6-8 | Adafruit, SparkFun |
| Qwiic/STEMMA Cable | 1 | $1-2 | Adafruit, SparkFun |
| Female-to-Female Jumpers | 3 | $1 | Amazon, AliExpress |
| USB Micro Cable | 1 | $1 | Amazon, local stores |

**Total: $14-19**

---

## 🔧 Option 1: Breadboard Build (Recommended)

### Parts You Need

**1. ESP32 DevKit Board**
- Any 30-pin ESP32-WROOM-32 DevKit
- Make sure it has 15 pins on each side
- $5-6 on Amazon/AliExpress

**2. Passive Piezo Buzzer Module**
Look for modules with **3 pins** (VCC, GND, I/O):
- **KY-006** Passive Buzzer Module ~$1-2
- **XY-T** Passive Buzzer Module ~$1-2
- Any "passive piezo buzzer module" with 3 pins

**Important:** Get "passive" not "active"! 
- ✅ **Passive** = can play different tones (what we need)
- ❌ **Active** = only one tone (won't work)

**3. Breadboard & Jumpers**
- 400-point breadboard (standard half-size)
- 3× male-to-male jumper wires
- Any color works, but red/black/yellow helps

### Assembly Steps

**Step 1: Insert ESP32 into Breadboard**
```
   Breadboard Layout (top view)
   ═══════════════════════════════
   ┌─────────────────────────────┐
   │  1  2  3  4  5 ... 15       │
   │  ●  ●  ●  ●  ●  ...  ●      │ ← ESP32 Left Side
   │                             │
   │  ●  ●  ●  ●  ●  ...  ●      │ ← ESP32 Right Side
   │  1  2  3  4  5 ... 15       │
   └─────────────────────────────┘
```

1. Straddle the ESP32 across the center gap
2. Push down gently but firmly
3. All 30 pins should be inserted

**Step 2: Connect Buzzer Module**

Buzzer modules typically have 3 pins:
- **S** or **I/O** = Signal pin
- **VCC** or **+** = Power (3.3V or 5V)
- **GND** or **-** = Ground

**Wiring:**
```
ESP32 DevKit          Buzzer Module
━━━━━━━━━━━━━━━━━━━━━━━━━━━━━━━━━━━━
    GPIO 25  ────────► S (Signal/I/O)
    
    3V3      ────────► VCC (+) or (leave unconnected*)
    
    GND      ────────► GND (-)
```

**Important Note:** Most passive buzzer modules are "self-powered" from the signal pin and don't need VCC. If yours has only 2 pins (S and GND), that's normal - just connect those two.

**Step 3: Insert Jumper Wires**

Using 3 male-to-male jumpers:

1. **GPIO 25 → Buzzer S**
   - Find GPIO 25 on ESP32 (usually labeled)
   - Insert one jumper end in same row as GPIO 25
   - Insert other end in Buzzer S pin row

2. **GND → Buzzer GND**
   - Find any GND pin on ESP32
   - Insert jumper in same row as GND
   - Insert other end in Buzzer GND pin row

3. **3V3 → Buzzer VCC** (optional, see note above)
   - Only if your buzzer has 3 pins
   - Connect 3V3 to VCC if buzzer requires it

**Visual Reference:**
```
Breadboard with ESP32 & Buzzer (side view):

     ESP32 (top down)                Buzzer Module
        
│ 3V3─●  USB  ●─GND │            ┌─────────────┐
│ EN ─●       ●─D23 │            │   ┌─────┐   │
│ D36─●       ●─D22 │  Jumpers   │   │ ))) │   │
│ D39─●       ●─TX  │  ═══════►  │   └─────┘   │
│ D34─●       ●─RX  │            │  S  +  GND  │
│ D35─●       ●─D21 │            └──●──●──●───┘
│ D32─●       ●─D19 │               │  │  │
│ D33─●       ●─D18 │               │  │  └──────┐
│ D25─●       ●─D5  │ ◄═════════════╝  │         │
│ D26─●       ●─D17 │                  │         │
│ D27─●       ●─D16 │                  │         │
│ D14─●       ●─D4  │                  │         │
│ D12─●       ●─D0  │ ◄════════════════╝         │
│ GND─●       ●─D2  │ ◄══════════════════════════╝
│ D13─●       ●─D15 │
```

**Step 4: Connect USB Cable**
- Plug micro USB cable into ESP32
- Connect to computer
- LED on ESP32 should light up

### Testing

1. Power on (ESP32 LED lights up)
2. Flash firmware: `pio run -t upload`
3. Monitor serial: `pio device monitor`
4. Should hear 6-note startup tune (Super Mario 1-2)
5. LED flashes when WiFi traffic detected
6. Buzzer chirps on Flock camera detection

**No sound?** See troubleshooting below.

---

## 🌿 Option 2: Grove System Build

Grove connectors are fool-proof - just plug and play!

### Parts You

 Need

**1. ESP32 with Grove Base**
- "ESP32 DevKit Grove Base Shield" ($8-10)
- Or "ESP32 + Grove Shield" combo
- Available on Seeed Studio, Amazon

**2. Grove Buzzer Module**
- "Grove - Buzzer" (passive) ~$3-4
- Item: 101020082 (Seeed Studio)
- Comes with Grove cable

### Assembly Steps

**Step 1: Attach Grove Base to ESP32**
1. Remove ESP32 from packaging
2. Align Grove Base Shield over ESP32 pins
3. Press down firmly to seat all pins
4. Base should click into place

**Step 2: Connect Grove Buzzer**
1. Take Grove cable (4-pin, 2mm pitch)
2. Plug one end into Buzzer module
3. Plug other end into **D25** port on Grove Base
4. Cable only fits one way - don't force it

**Step 3: Flash & Test**
1. Connect USB cable
2. Flash firmware
3. Should hear startup tune immediately
4. Grove system auto-configures - zero setup needed!

**Why Grove?**
- ✅ No wiring errors possible
- ✅ Professional-looking build
- ✅ Hot-swappable modules
- ✅ Sturdy connections (vibration-proof)

---

## 🔌 Option 3: Qwiic/STEMMA Build

Similar to Grove but uses I2C... except we're wiring it manually to GPIO 25.

### Parts You Need

**1. ESP32 DevKit (any)**
- Standard 30-pin ESP32
- $5-6

**2. Qwiic/STEMMA Buzzer Breakout**
- SparkFun Qwiic Buzzer (~$7)
- Or Adafruit STEMMA-compatible buzzer
- Comes with Qwiic cable

**3. Female-to-Female Jumpers**
- 3× jumpers to adapt Qwiic to GPIO
- $1 for pack of 40

### Assembly Steps

**Step 1: Identify Qwiic Buzzer Pins**

Qwiic buzzers usually have:
- **SIG** = Signal
- **VCC** = 3.3V or 5V
- **GND** = Ground
- **I2C pins** = (ignore, we're using SIG)

**Step 2: Wire with Jumpers**

```
ESP32 Pin   →  Female Jumper  →  Buzzer Pin
━━━━━━━───────────────────────────━━━━━━━━
GPIO 25     →  (any color)    →  SIG
GND         →  Black          →  GND  
3V3         →  Red            →  VCC (optional)
```

1. Take 3 female-to-female jumpers
2. Plug one end into ESP32 GPIO 25 pin
3. Plug other end into Buzzer SIG pin
4. Repeat for GND and VCC (if needed)

**Why Qwiic?**
- Compact, professional modules
- Same ecosystem as SparkFun/Adafruit
- Easier to expand with other sensors later

---

## 🧰 Recommended Products (Links)

### Breadboard Build Components

**ESP32 DevKit:**
- Search: "ESP32 DevKit V1 WROOM-32"
- Amazon: ~$6 with Prime shipping
- AliExpress: ~$3-4 (2-3 week shipping)

**Passive Buzzer Module:**
- Search: "KY-006 passive buzzer module"
- Amazon: ~$8 for 5-pack
- AliExpress: ~$1 each

**Breadboard & Jumpers:**
- Search: "400 point breadboard jumper wire kit"
- Amazon: ~$10 for complete kit
- Includes breadboard + 140 jumpers

### Grove Build Components

**Grove Base Shield:**
- Search: "ESP32 Grove base shield"
- Seeed Studio: Official source
- Amazon: Usually in stock

**Grove Buzzer:**
- Search: "Grove buzzer passive"
- Seeed: Part #101020082
- Amazon: Also available

### Complete Kits

**All-in-One ESP32 Breadboard Kit:**
- Search: "ESP32 breadboard kit"
- Includes: ESP32 + breadboard + jumpers + LEDs + buzzers
- Amazon: $15-20
- Perfect for beginners - everything included!

---

## 🐛 Troubleshooting

### No Startup Sound

**Possible causes:**

1. **Active vs Passive Buzzer**
   - **Problem:** You have an "active" buzzer (won't play tones)
   - **Solution:** Order a "passive" buzzer module
   - **How to tell:** Active buzzers have a black chip on back

2. **Wrong GPIO Pin**
   - **Problem:** Buzzer connected to wrong pin
   - **Solution:** Verify GPIO 25 connection (count from end)
   - **Check:** Use multimeter or LED to test pin

3. **Power Issue**
   - **Problem:** USB port not providing enough current
   - **Solution:** Try powered USB hub or different port
   - **Check:** Does onboard ESP32 LED light up?

4. **Buzzer Polarity**
   - **Problem:** Some passive buzzers are polarized
   - **Solution:** Swap the Signal and GND wires
   - **Test:** Try both orientations

5. **Firmware Not Using GPIO 25**
   - **Problem:** Old firmware version
   - **Solution:** Re-download latest main.cpp
   - **Verify:** Check line 12 has `#define BUZZER_PIN 25`

### Buzzer Sounds Distorted

**Causes & Fixes:**

- **Too much current:** Add 100Ω resistor between GPIO 25 and buzzer Signal
- **Wrong voltage:** Some buzzers need 5V, try connecting VCC to VIN (5V) instead of 3V3
- **EMI interference:** Move buzzer away from ESP32 antenna area

### Connection Keeps Falling Out

**Breadboard connections:**
- Insert pins fully - should feel firm
- If loose, try different breadboard rows
- Clean pin legs with isopropyl alcohol

**Grove connections:**
- Push connector in firmly until it clicks
- Cable might be backwards - try flipping it
- Check for bent pins in connector

### Need to Disable Buzzer Temporarily?

Edit `main.cpp` line 13:
```cpp
#define USE_BUZZER 0  // Change 1 to 0
```

Re-upload firmware. LED still works for visual feedback.

---

## ⚡ Quick Start Checklist

- [ ] ESP32 DevKit purchased ($5-6)
- [ ] Passive buzzer module ordered ($1-2)
- [ ] Breadboard & jumpers acquired ($2)
- [ ] USB cable ready (Micro USB)
- [ ] PlatformIO installed (VS Code extension)
- [ ] Firmware downloaded (`flock-you-esp32/firmware/`)
- [ ] ESP32 inserted into breadboard (straddles center)
- [ ] Buzzer GPIO 25 → Signal wire connected
- [ ] Buzzer GND → Ground wire connected
- [ ] USB plugged in (ESP32 LED lights up)
- [ ] Firmware flashed (`pio run -t upload`)
- [ ] Startup tune plays (6 notes)
- [ ] Serial monitor shows scanning
- [ ] Ready to detect!

---

## 🎯 Next Step: 3D Printed Case

Once your solderless build is working, check out `CASE_DESIGN.md` for a 3D printable enclosure that holds everything together professionally!

The case design accommodates:
- Standard ESP32 DevKit (30-pin)
- Breadboard-mounted buzzer
- USB cable strain relief
- Mounting holes for car dashboard
- LED light pipe for onboard LED

---

## 💡 Pro Tips

### Tip 1: Color-Code Your Wires
- **Red** = Power (3V3 or VCC)
- **Black** = Ground (GND)
- **Yellow** = Signal (GPIO 25)

Makes troubleshooting easier!

### Tip 2: Test Buzzer First
Before assembling, test buzzer independently:
```cpp
void setup() {
  pinMode(25, OUTPUT);
  tone(25, 1000);  // 1kHz tone
  delay(1000);
  noTone(25);
}
```

Should hear 1 second beep.

### Tip 3: Secure for Vehicle Use
If using in a car:
- Use velcro strips to mount breadboard
- Zip-tie USB cable for strain relief
- Consider Grove system for vibration resistance

### Tip 4: Battery Power
For portable use without USB:
- Use 18650 battery holder with 5V boost
- Connect to ESP32 VIN pin (5V input)
- Typical runtime: 6-8 hours

---

## 📷 Visual Assembly Guide

See the `/hardware/assembly_photos/` folder for:
- High-res photos of each assembly step
- Close-ups of correct pin connections
- Common mistake photos (what NOT to do)
- Finished build examples

---

## ✅ Success!

You now have a **fully functional Flock-You detector** without touching a soldering iron!

**Hardware cost:** $9-11  
**Assembly time:** 5-10 minutes  
**Skill required:** Plug things in  
**Detection accuracy:** Same as $85 OUI-SPY board  

**Next steps:**
1. Flash firmware and test
2. Drive near known Flock camera locations
3. Build 3D printed case (optional)
4. Add GPS module for wardriving (advanced)

Happy detecting! 🎉

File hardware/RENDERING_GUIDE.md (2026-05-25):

# OpenSCAD Model Rendering Guide

## 🎨 Generating Product Images

This guide shows you how to create professional renders of the 3D case models for documentation, marketing, and publishing.

---

## ⚡ Quick Start

### Option 1: Automated Script (Recommended)

```bash
cd hardware
./render_models.sh
```

This generates 5 high-quality renders:
- `case-base-iso.png` - Base isometric view
- `case-base-top.png` - Base top-down view
- `case-lid-iso.png` - Lid isometric view
- `led-pipe.png` - Light pipe detail
- `assembly-exploded.png` - Full assembly

**Output:** `hardware/renders/` folder

### Option 2: Manual OpenSCAD GUI

1. Open `openscad/flock-you-case.scad` in OpenSCAD
2. Uncomment the part you want (lines at bottom)
3. Press **F6** to render (may take 30-60 seconds)
4. **F12** or View → Top/Bottom/etc for different angles
5. File → Export → Export as Image

---

## 🖥️ Installing OpenSCAD

### macOS
```bash
brew install openscad
```

### Linux (Ubuntu/Debian)
```bash
sudo apt-get update
sudo apt-get install openscad
```

### Windows
Download from: [openscad.org/downloads.html](https://openscad.org/downloads.html)

### Verify Installation
```bash
openscad --version
```

Should output: `OpenSCAD version 2021.01` (or newer)

---

## 📸 Render Settings

### For Documentation (High Quality)
```bash
openscad -o output.png \
    --imgsize=1920,1080 \
    --render \
    --colorscheme="Tomorrow Night" \
    --camera="100,80,60,55,0,25,300" \
    model.scad
```

### For Web (Optimized Size)
```bash
openscad -o output.png \
    --imgsize=1200,675 \
    --render \
    --colorscheme="Cornfield" \
    model.scad
```

### For Print (Ultra High-Res)
```bash
openscad -o output.png \
    --imgsize=3840,2160 \
    --render \
    --colorscheme="Tomorrow Night" \
    model.scad
```

---

## 🎨 Color Schemes

OpenSCAD includes several built-in themes:

| Scheme | Style | Best For |
|---|---|---|
| **Tomorrow Night** | Dark, modern | Product shots, documentation |
| **Cornfield** | Light, clean | Web, light backgrounds |
| **Metallic** | Gray metallic | Professional renders |
| **Sunset** | Warm tones | Marketing materials |
| **Nature** | Green/brown | Eco-friendly branding |

Test them all:
```bash
for scheme in "Tomorrow Night" "Cornfield" "Metallic" "Sunset"; do
    openscad -o "test-$scheme.png" \
        --colorscheme="$scheme" \
        --render \
        openscad/flock-you-case.scad
done
```

---

## 📐 Camera Positioning

### Understanding Camera Parameters
```bash
--camera="X,Y,Z,RotX,RotY,RotZ,Distance"
```

**Examples:**

**Isometric View** (default):
```bash
--camera="100,80,60,55,0,25,300"
```

**Top-Down:**
```bash
--camera="35,25,100,0,0,0,200"
```

**Front View:**
```bash
--camera="0,-100,25,90,0,0,200"
```

**Side View:**
```bash
--camera="100,0,25,90,0,90,200"
```

**Close-Up Detail:**
```bash
--camera="50,40,30,55,0,25,150"
```

---

## 🎬 Creating Animations

### Rotating Turntable Animation

```bash
#!/bin/bash
# Generate 36 frames (10° rotation each)
for i in {0..35}; do
    angle=$((i * 10))
    openscad -o "frame_$(printf "%03d" $i).png" \
        --imgsize=1920,1080 \
        --render \
        --colorscheme="Tomorrow Night" \
        --camera="100,80,60,55,0,$angle,300" \
        openscad/flock-you-case.scad
done

# Combine into GIF (requires ImageMagick)
convert -delay 5 -loop 0 frame_*.png animation.gif

# Or video (requires ffmpeg)
ffmpeg -framerate 30 -i frame_%03d.png -c:v libx264 animation.mp4
```

### Exploded Assembly Animation

Modify the SCAD file to use a parameter:
```openscad
// Add to top of file
explode_distance = 0;  // Animate from 0 to 30

// In assembly:
translate([0, 0, case_height + explode_distance])
    case_lid();
```

Then render with increasing values.

---

## 🖼️ Post-Processing

### Optimizing File Size

```bash
# Install optimization tools
brew install pngquant optipng  # macOS
sudo apt-get install pngquant optipng  # Linux

# Optimize PNG (90% quality, huge size reduction)
pngquant --quality=85-95 input.png
optipng -o7 output.png

# Typical savings: 2MB → 300KB
```

### Adding Backgrounds

```bash
# Transparent background (for overlays)
convert input.png -fuzz 2% -transparent white output.png

# Add gradient background
convert input.png \
    \( +clone -fill "gradient:white-lightgray" \
       -draw "color 0,0 reset" \) \
    +swap -compose Over -composite \
    output.png

# Add shadow
convert input.png \
    \( +clone -background black -shadow 80x3+5+5 \) \
    +swap -background white -layers merge +repage \
    output.png
```

### Image Grid (Multiple Views)

```bash
# 2×2 grid of different angles
montage case-base-*.png case-lid-*.png \
    -tile 2x2 -geometry +10+10 \
    -background white \
    grid.png
```

---

## 📊 Batch Rendering All Parts

### Complete Render Script

Create `render_all_parts.sh`:

```bash
#!/bin/bash

PARTS=("case_base" "case_lid" "led_light_pipe" "mounting_bracket")
VIEWS=("iso" "top" "front" "side")

CAMERAS=(
    "100,80,60,55,0,25,300"      # Isometric
    "35,25,100,0,0,0,200"        # Top
    "0,-100,25,90,0,0,200"       # Front
    "100,0,25,90,0,90,200"       # Side
)

for part in "${PARTS[@]}"; do
    echo "Rendering $part..."
    
    # Edit SCAD to show only this part
    sed -i.bak "s|^//\($part\);|\1;|" openscad/flock-you-case.scad
    
    for i in "${!VIEWS[@]}"; do
        view="${VIEWS[$i]}"
        cam="${CAMERAS[$i]}"
        
        openscad -o "renders/${part}-${view}.png" \
            --imgsize=1920,1080 \
            --render \
            --colorscheme="Tomorrow Night" \
            --camera="$cam" \
            openscad/flock-you-case.scad
    done
    
    # Restore SCAD
    mv openscad/flock-you-case.scad.bak openscad/flock-you-case.scad
done

echo "All renders complete!"
```

---

## 🎯 Use Cases

### For GitHub README
```markdown
![Case Assembly](hardware/renders/assembly-exploded.png)

*Professional 3D printed enclosure with snap-fit lid*
```

### For Product Page
- Hero image: Isometric assembled view
- Features grid: Top, front, side views
- Detail shots: Light pipe, mounting holes
- Animation: 360° turntable GIF

### For Build Guide
- Step 1: Base with labels
- Step 2: Components placement
- Step 3: Lid installation
- Final: Complete assembly

### For Marketing
- High-res hero shot (4K)
- Lifestyle shots (in car, on desk)
- Size comparison (next to phone)
- Materials showcase (different colors)

---

## 💡 Pro Tips

### Faster Preview Rendering
```bash
# Use --preview instead of --render for quick tests
openscad -o preview.png \
    --imgsize=800,600 \
    --colorscheme="Tomorrow Night" \
    model.scad
# Renders in ~2 seconds vs 30+ seconds
```

### Consistent Lighting
Always use the same camera/lighting for product lineup:
```bash
CAMERA="100,80,60,55,0,25,300"
SCHEME="Tomorrow Night"
SIZE="1920,1080"

# Save as template and reuse
```

### Quality vs Speed Trade-off
- **Preview** (2s): Draft, testing angles
- **Normal render** (30s): Documentation, web
- **High-quality** (2min): Print, hero images
- **Ultra** (10min): Marketing, large prints

---

## 🐛 Troubleshooting

### "Command not found: openscad"
Install OpenSCAD (see installation section above)

### Render takes forever (>5 minutes)
- Reduce `$fn` values in SCAD (32 → 16)
- Use `--preview` for testing
- Check CPU usage (should be 100%)

### Black/blank output image
- Verify SCAD file has no errors (test in GUI first)
- Check camera position (too far/close?)
- Try different color scheme

### "Cannot create output file"
- Check write permissions on output directory
- Ensure path exists: `mkdir -p renders/`
- Check disk space

### Jagged edges / low quality
- Increase resolution: `--imgsize=3840,2160`
- Increase `$fn` in SCAD file
- Use `--render` not `--preview`

---

## 📚 Learning Resources

### Official Docs
- [OpenSCAD Manual](https://en.wikibooks.org/wiki/OpenSCAD_User_Manual)
- [Camera Parameters](https://en.wikibooks.org/wiki/OpenSCAD_User_Manual/The_OpenSCAD_Language#Camera)
- [Command Line](https://en.wikibooks.org/wiki/OpenSCAD_User_Manual/Using_OpenSCAD_in_a_command_line_environment)

### Video Tutorials
- "OpenSCAD Rendering Guide" - YouTube
- "Product Photography with OpenSCAD" - YouTube

### Example Galleries
- Thingiverse (search "openscad renders")
- Printables (filter by "openscad")

---

## ✅ Render Checklist

Before publishing:

- [ ] All parts rendered (base, lid, pipe, bracket)
- [ ] Multiple views (iso, top, side, front)
- [ ] Consistent lighting/camera across set
- [ ] High resolution (1920×1080 minimum)
- [ ] File size optimized (<500KB each)
- [ ] Assembly/exploded view included
- [ ] Optional: 360° animation
- [ ] Optional: Size reference added
- [ ] Images added to documentation
- [ ] Credited in README

---

## 🎉 You're Ready!

Run the rendering script or explore manual rendering.

**Quick command:**
```bash
cd hardware && ./render_models.sh
```

**Output:** Professional product images ready for documentation, marketing, and publication!

Happy rendering! 📸

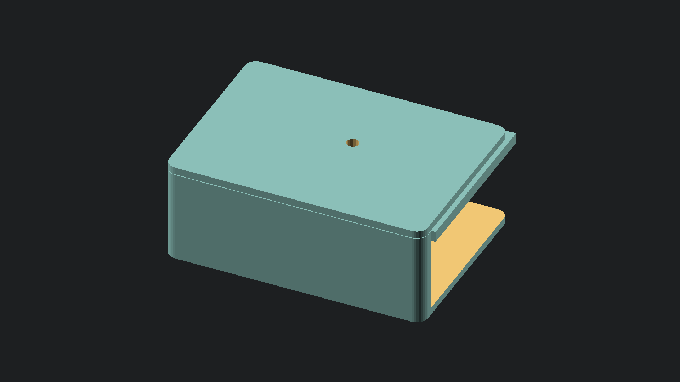
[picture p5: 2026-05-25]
hardware/renders/assembly-exploded.png

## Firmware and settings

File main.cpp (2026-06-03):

#include <Arduino.h>
#include <WiFi.h>
#include "esp_wifi.h"
#include <ctype.h>
#include <string.h>
#include <SPIFFS.h>
// NeoPixel only needed for Echo/Lite variants
#if defined(USE_M5ATOM_ECHO) || defined(USE_M5ATOM_LITE)
#include <Adafruit_NeoPixel.h>
#endif

// M5Atom support - using NeoPixel for LED only (NO M5Atom library - it's buggy!)
#if defined(USE_M5ATOM_ECHO) || defined(USE_M5ATOM_LITE)
  #define USE_M5ATOM 1
  #define LED_PIN 27
  #define NUM_LEDS 1  // Atom Lite has 1 LED (Matrix has 25)
  #define BUTTON_PIN 39  // M5Atom button on GPIO39
  Adafruit_NeoPixel strip(NUM_LEDS, LED_PIN, NEO_GRB + NEO_KHZ800);
#endif

// Atom VoiceS3R (ESP32-S3-PICO-1-N8R8): native USB-CDC, no user RGB LED.
// Speaker: ES8311 codec + NS4150B amp, driven via M5Unified over I2S.
// Button: GPIO41.  Amp enable: GPIO18 (NS4150_CTR — M5Unified handles it).
#if defined(USE_M5ATOM_VOICES3R)
  #include <M5Unified.h>
  #define BUTTON_PIN 41
#endif

// ============================================================
// CONFIG
// ============================================================

// TESTING MODE: Set to 1 to blink/alert on ANY WiFi traffic (for testing)
// Set to 0 for normal operation (Flock OUI detection only)
// Can be overridden at build time via -DTESTING_MODE=1 in platformio.ini
#ifndef TESTING_MODE
  #define TESTING_MODE 0
#endif

#if defined(USE_M5ATOM_ECHO)
  // M5Atom Echo: Built-in speaker + 5x5 LED matrix
  #define BUZZER_PIN 25
  #define USE_BUZZER 1
  #define USE_M5_SPEAKER 1
  #define USE_LED 1
  #define USE_LED_MATRIX 1
  #define LED_FLASH_MS 120
#elif defined(USE_M5ATOM_LITE)
  // M5Atom Lite: 5x5 LED matrix only (no speaker)
  #define BUZZER_PIN 25
  #define USE_BUZZER 0
  #define USE_LED 1
  #define USE_LED_MATRIX 1
  #define LED_FLASH_MS 120
#elif defined(USE_M5ATOM_VOICES3R)
  // Atom VoiceS3R: ES8311 I2S speaker via M5Unified. No RGB LED.
  #define USE_BUZZER 0
  #define USE_M5_SPEAKER 1   // M5.Speaker.tone() — requires M5Unified
  #define USE_LED 0
  #define LED_FLASH_MS 0
#else
  // Standard ESP32 DevKit
  #define BUZZER_PIN 25
  #define USE_BUZZER 1
  #define LED_PIN 2
  #define USE_LED 1
  #define LED_ACTIVE_HIGH 1
  #define LED_FLASH_MS 120
#endif

#define MIRROR_SERIAL    1
#define MIRROR_TX_PIN    17
#define MIRROR_BAUD      115200

#define CHANNEL_MODE_FULL_HOP   0
#define CHANNEL_MODE_CUSTOM     1
#define CHANNEL_MODE_SINGLE     2

#define CHANNEL_MODE CHANNEL_MODE_CUSTOM
#define CHANNEL_DWELL_MS 350
#define SINGLE_CHANNEL 1

static const uint8_t customChannels[]  = {1, 6, 11};
static const size_t  customChannelCount = sizeof(customChannels) / sizeof(customChannels[0]);

static const uint8_t fullHopChannels[] = {1,2,3,4,5,6,7,8,9,10,11};
static const size_t  fullHopChannelCount = sizeof(fullHopChannels) / sizeof(fullHopChannels[0]);

#define HEARTBEAT_MS    30000
#define RSSI_MIN        -95
#define ALERT_COOLDOWN_MS 5000

// Audio cadence: two fast ascending beeps on a NEW MAC, then while any
// target is still in range (seen within HB_DEVICE_ACTIVE_MS), two monotone
// heartbeat beeps every HB_BEEP_INTERVAL_MS.
#define HB_DEVICE_ACTIVE_MS    3000
#define HB_BEEP_INTERVAL_MS    10000
// A MAC we haven't heard from in REDISCOVER_MS counts as a fresh discovery
// next time it shows up — fires the ascending chirp again. Shorter than a
// Flock's burst-sleep gap would mean false chirps; longer means you'd miss
// a drive-away/return. 30 s is a good middle ground.
#define REDISCOVER_MS          30000
#define NEW_CHIRP_LO_HZ        2000
#define NEW_CHIRP_HI_HZ        2800
#define NEW_CHIRP_NOTE_MS      55
#define NEW_CHIRP_GAP_MS       25
#define HB_BEEP_HZ             1500
#define HB_BEEP_NOTE_MS        70
#define HB_BEEP_GAP_MS         70

#define ENABLE_SSID_MATCH 0
#define CHECK_ADDR1 1   // dst/rx — catches Flock STAs receiving probe responses
#define CHECK_ADDR3 0   // bssid fallback for randomised addr2
static const char* target_ssid_keywords[] = { "flock" };
static const size_t SSID_KEYWORD_COUNT = sizeof(target_ssid_keywords) / sizeof(target_ssid_keywords[0]);

#define STOP_ON_SSID_HIT 0
#define STOP_ON_OUI_HIT  0
#define PROCESS_MGMT_FRAMES 1
#define PROCESS_DATA_FRAMES 1

// Persistence
#define MAX_DETECTIONS       200
#define FY_SESSION_FILE      "/session.json"
#define FY_SESSION_TMP       "/session.tmp"
#define FY_PREV_FILE         "/prev_session.json"
#define AUTOSAVE_INTERVAL_MS 60000

// ============================================================
// TARGET OUI LIST  (all lowercase, colons only)
// ============================================================

static const char* target_ouis[] = {
  "70:c9:4e", "3c:91:80", "d8:f3:bc", "80:30:49", "b8:35:32",
  "14:5a:fc", "74:4c:a1", "08:3a:88", "9c:2f:9d", "c0:35:32",
  "94:08:53", "e4:aa:ea", "f4:6a:dd", "f8:a2:d6", "24:b2:b9",
  "00:f4:8d", "d0:39:57", "e8:d0:fc", "e0:4f:43", "b8:1e:a4",
  "70:08:94", "58:8e:81", "ec:1b:bd", "3c:71:bf", "58:00:e3",
  "90:35:ea", "5c:93:a2", "64:6e:69", "48:27:ea", "a4:cf:12",
  // Contributed by Michael / DeFlockJoplin — discovered via wildcard-probe
  // + OUI signature during field testing. The 12th camera in his drive-test
  // used this prefix and wasn't in @NitekryDPaul's original 30.
  "82:6b:f2"

};
static const size_t OUI_COUNT = sizeof(target_ouis) / sizeof(target_ouis[0]);

// Pre-compiled byte table — populated once in setup(), never touched again.
// Keeps matchOuiRaw entirely in IRAM with no flash-resident function calls.
static uint8_t oui_bytes[OUI_COUNT][3];

// ============================================================
// ALERT QUEUE  (callback → loop, avoids Serial in WiFi task)
// ============================================================

#define ALERT_QUEUE_SIZE 32

typedef enum : uint8_t {
  ALERT_OUI_ADDR2       = 0,
  ALERT_OUI_ADDR1       = 1,
  ALERT_OUI_ADDR3       = 2,
  ALERT_SSID            = 3,
  // Probe Request + wildcard SSID (tag 0, length 0) from a known-OUI addr2.
  // Tight signature from Michael / DeFlockJoplin field research:
  //   https://github.com/DeflockJoplin/flock-you
  ALERT_WILDCARD_PROBE  = 4,
} AlertType;

typedef struct {
  AlertType type;
  uint8_t   mac[6];
  int8_t    rssi;
  uint8_t   channel;
  char      ssid[33];     // populated for SSID hits
  char      frameKind[12];
} AlertEntry;

static volatile AlertEntry alertQueue[ALERT_QUEUE_SIZE];
static volatile size_t alertHead = 0;  // written by callback
static volatile size_t alertTail = 0;  // read by loop()
static portMUX_TYPE    queueMux  = portMUX_INITIALIZER_UNLOCKED;

static void IRAM_ATTR enqueueAlert(AlertType type, const uint8_t* mac, int8_t rssi,
                                    uint8_t ch, const char* ssid, const char* kind) {
  portENTER_CRITICAL_ISR(&queueMux);
  size_t next = (alertHead + 1) % ALERT_QUEUE_SIZE;
  if (next == alertTail) {                         // drop if full — loop() is behind
    portEXIT_CRITICAL_ISR(&queueMux);
    return;
  }

  AlertEntry* e = (AlertEntry*)&alertQueue[alertHead];
  e->type    = type;
  e->rssi    = rssi;
  e->channel = ch;
  memcpy((void*)e->mac, mac, 6);

  if (ssid)  { strncpy((char*)e->ssid,      ssid, 32); ((char*)e->ssid)[32] = '\0'; }
  else        { ((char*)e->ssid)[0] = '\0'; }

  if (kind)  { strncpy((char*)e->frameKind, kind, 11); ((char*)e->frameKind)[11] = '\0'; }
  else        { ((char*)e->frameKind)[0] = '\0'; }

  alertHead = next;
  portEXIT_CRITICAL_ISR(&queueMux);
}

// ============================================================
// DETECTION TABLE  (on-device storage, persisted to SPIFFS)
// ============================================================
//
// Single-threaded: only touched from loop() — drainAlertQueue() adds, and
// fySaveSession() reads. No mutex needed. The WiFi-task callback never
// touches this table; it only writes to the lock-free alert ring buffer.

typedef struct {
  char     mac[18];
  char     method[16];     // "oui_addr2" / "oui_addr1" / "oui_addr3" / "ssid"
  int8_t   rssi;
  uint8_t  channel;
  uint32_t firstSeen;      // millis() at first hit
  uint32_t lastSeen;       // millis() at latest hit
  uint16_t count;
  char     ssid[33];       // "" unless an SSID hit populated it
} FYDetection;

static FYDetection fyDet[MAX_DETECTIONS];
static int           fyDetCount       = 0;
static bool          fySpiffsReady    = false;
static bool          fyDirty          = false;
static unsigned long fyLastSaveAt     = 0;
static int           fyLastSaveCount  = 0;

// ============================================================
// STATE
// ============================================================

static uint8_t  currentChannel = 1;
static size_t   customChannelIndex = 0;
static size_t   fullHopIndex = 0;
static unsigned long lastHop = 0;
static unsigned long lastHeartbeat = 0;
static volatile bool sniffingStopped = false;

// Dedupe table (small circular, avoids single-slot eviction bug).
// This is the *serial-rate-limit* dedup — it suppresses beep + emit within
// ALERT_COOLDOWN_MS of a prior hit on the same MAC. The detection table
// (above) still counts every hit regardless of this suppression.
#define DEDUPE_SLOTS 8
static struct {
  char mac[18];
  unsigned long ts;
} dedupeTable[DEDUPE_SLOTS];
static size_t dedupeIdx = 0;

// LED one-shot pulse timer
static volatile unsigned long ledOffAt = 0;

// Heartbeat audio state: last time any target was seen, last time the
// heartbeat beep-pair was played. When nothing has been seen for
// HB_DEVICE_ACTIVE_MS the heartbeat stops until the next new detection.
static unsigned long fyLastTargetSeen  = 0;
static unsigned long fyLastHeartbeatAt = 0;

// ============================================================
// 802.11 HEADER
// ============================================================

typedef struct __attribute__((packed)) {
  uint16_t frame_ctrl;
  uint16_t duration;
  uint8_t  addr1[6];
  uint8_t  addr2[6];
  uint8_t  addr3[6];
  uint16_t seq_ctrl;
} wifi_ieee80211_mac_hdr_t;

// ============================================================
// HELPERS
// ============================================================

// Dual-output: prints to both Serial (USB) and Serial1 (GPIO43)
static char _dualBuf[384];

static void dualPrintf(const char* fmt, ...) __attribute__((format(printf, 1, 2)));
static void dualPrintf(const char* fmt, ...) {
  va_list args;
  va_start(args, fmt);
  int n = vsnprintf(_dualBuf, sizeof(_dualBuf), fmt, args);
  va_end(args);
  if (n > 0) {
    Serial.write(_dualBuf, n);
#if MIRROR_SERIAL && !defined(USE_M5ATOM_VOICES3R)
    Serial1.write(_dualBuf, n);
#endif
  }
}

static void dualPrintln(const char* str) {
  Serial.println(str);
#if MIRROR_SERIAL && !defined(USE_M5ATOM_VOICES3R)
  Serial1.println(str);
#endif
}

static inline void ledSet(bool on) {
#if USE_LED
#if defined(USE_LED_MATRIX)
  // M5Atom: Use NeoPixel library for LED control
  if (on) {
    strip.setPixelColor(0, strip.Color(0, 0, 255));  // Blue
  } else {
    strip.setPixelColor(0, strip.Color(0, 0, 0));    // Off
  }
  strip.show();
#elif LED_ACTIVE_HIGH
  digitalWrite(LED_PIN, on ? HIGH : LOW);
#else
  digitalWrite(LED_PIN, on ? LOW  : HIGH);
#endif
#endif
}

static void ledFlash(unsigned ms) {
#if USE_LED
  ledSet(true);
  ledOffAt = millis() + ms;
  if (ledOffAt == 0) ledOffAt = 1;  // avoid the "off" sentinel
#endif
}

static void ledTick() {
#if USE_LED
  if (ledOffAt && (long)(millis() - ledOffAt) >= 0) {
    ledSet(false);
    ledOffAt = 0;
  }
#endif
}

static void buzzerBeep(unsigned int ms) {
#if USE_BUZZER
  digitalWrite(BUZZER_PIN, HIGH); delay(ms); digitalWrite(BUZZER_PIN, LOW);
#endif
}

// Two fast ascending beeps — played on the FIRST sighting of a MAC.
static void newDetectChirp() {
#if USE_BUZZER
  tone(BUZZER_PIN, NEW_CHIRP_LO_HZ); delay(NEW_CHIRP_NOTE_MS); noTone(BUZZER_PIN);
  delay(NEW_CHIRP_GAP_MS);
  tone(BUZZER_PIN, NEW_CHIRP_HI_HZ); delay(NEW_CHIRP_NOTE_MS); noTone(BUZZER_PIN);
#elif defined(USE_M5_SPEAKER) && USE_M5_SPEAKER
  M5.Speaker.tone(NEW_CHIRP_LO_HZ, NEW_CHIRP_NOTE_MS); delay(NEW_CHIRP_NOTE_MS + NEW_CHIRP_GAP_MS);
  M5.Speaker.tone(NEW_CHIRP_HI_HZ, NEW_CHIRP_NOTE_MS); delay(NEW_CHIRP_NOTE_MS);
  M5.Speaker.stop();
#endif
}

// Two monotone beeps — periodic heartbeat while at least one target is still
// in range (last seen within HB_DEVICE_ACTIVE_MS).
static void heartbeatBeep() {
#if USE_BUZZER
  tone(BUZZER_PIN, HB_BEEP_HZ); delay(HB_BEEP_NOTE_MS); noTone(BUZZER_PIN);
  delay(HB_BEEP_GAP_MS);
  tone(BUZZER_PIN, HB_BEEP_HZ); delay(HB_BEEP_NOTE_MS); noTone(BUZZER_PIN);
#elif defined(USE_M5_SPEAKER) && USE_M5_SPEAKER
  M5.Speaker.tone(HB_BEEP_HZ, HB_BEEP_NOTE_MS); delay(HB_BEEP_NOTE_MS + HB_BEEP_GAP_MS);
  M5.Speaker.tone(HB_BEEP_HZ, HB_BEEP_NOTE_MS); delay(HB_BEEP_NOTE_MS);
  M5.Speaker.stop();
#endif
}
static void startupBeep() {
#if USE_BUZZER
  // First 6 notes of SMB World 1-2 (underground). Koji Kondo's descending
  // pattern: C5 → C4 → A4 → A3 → G#4 → G#3 (alternating-octave pairs).
  static const uint16_t notes[6] = { 523, 262, 440, 220, 415, 208 };
  for (int i = 0; i < 6; i++) {
    tone(BUZZER_PIN, notes[i]);
    delay((i == 5) ? 160 : 95);
    noTone(BUZZER_PIN);
    if (i < 5) delay(22);
  }
#elif defined(USE_M5_SPEAKER) && USE_M5_SPEAKER
  // SMB World 1-1 overworld opening riff: E E _E_ C E G (low G)
  // Frequencies: E5=659 C5=523 G5=784 G4=392
  static const uint16_t notes[] = { 659, 659, 659, 523, 659, 784, 392 };
  static const uint16_t durs[]  = { 100, 100, 100, 100, 100, 300, 300 };
  static const uint8_t  gaps[]  = {  80,  80,  80,   0,   0,  80,   0 };
  for (size_t i = 0; i < sizeof(notes)/sizeof(notes[0]); i++) {
    M5.Speaker.tone(notes[i], durs[i]);
    delay(durs[i]);
    if (gaps[i]) { M5.Speaker.stop(); delay(gaps[i]); }
  }
  M5.Speaker.stop();
#endif
}

static void macToStr(const uint8_t* mac, char* buf, size_t len) {
  snprintf(buf, len, "%02x:%02x:%02x:%02x:%02x:%02x",
           mac[0], mac[1], mac[2], mac[3], mac[4], mac[5]);
}
static void ouiFromMac(const uint8_t* mac, char* buf, size_t len) {
  snprintf(buf, len, "%02x:%02x:%02x", mac[0], mac[1], mac[2]);
}

static void precompileOuis() {
  for (size_t i = 0; i < OUI_COUNT; i++) {
    const char* o  = target_ouis[i];
    oui_bytes[i][0] = (uint8_t)strtol(o,     nullptr, 16);
    oui_bytes[i][1] = (uint8_t)strtol(o + 3, nullptr, 16);
    oui_bytes[i][2] = (uint8_t)strtol(o + 6, nullptr, 16);
  }
}

// Bit 0 of byte 0 set = multicast/broadcast — never a real device transmitter or receiver
// we care about. Guards addr1 checks against 01:xx, 33:33:xx, ff:ff:ff:ff:ff:ff etc.
static inline bool IRAM_ATTR isMulticast(const uint8_t* mac) {
  return mac[0] & 0x01;
}

static bool IRAM_ATTR matchOuiRaw(const uint8_t* mac) {
  // Locally-administered (randomised) MACs have bit 1 of byte 0 set.
  // Fixed infrastructure devices never use them — skip immediately.
  if (mac[0] & 0x02) return false;

  for (size_t i = 0; i < OUI_COUNT; i++) {
    if (mac[0] == oui_bytes[i][0] &&
        mac[1] == oui_bytes[i][1] &&
        mac[2] == oui_bytes[i][2]) return true;
  }
  return false;
}

static char* strcasestr_local(const char* haystack, const char* needle) {
  if (!*needle) return (char*)haystack;
  for (; *haystack; ++haystack) {
    const char* h = haystack; const char* n = needle;
    while (*h && *n && tolower((unsigned char)*h) == tolower((unsigned char)*n)) { ++h; ++n; }
    if (!*n) return (char*)haystack;
  }
  return nullptr;
}
static bool matchSsidKeyword(const char* ssid) {
  for (size_t i = 0; i < SSID_KEYWORD_COUNT; i++)
    if (strcasestr_local(ssid, target_ssid_keywords[i])) return true;
  return false;
}

static const char* channelModeName() {
  switch (CHANNEL_MODE) {
    case CHANNEL_MODE_FULL_HOP: return "FULL_HOP";
    case CHANNEL_MODE_CUSTOM:   return "CUSTOM";
    case CHANNEL_MODE_SINGLE:   return "SINGLE";
    default:                    return "UNKNOWN";
  }
}

static inline uint16_t channelFreqMhz(uint8_t ch) {
  return (ch >= 1 && ch <= 14) ? (uint16_t)(2407 + 5 * ch) : 0;
}

static bool shouldSuppressDuplicate(const char* macStr) {
  unsigned long now = millis();
  for (size_t i = 0; i < DEDUPE_SLOTS; i++) {
    if (strcmp(dedupeTable[i].mac, macStr) == 0) {
      if ((now - dedupeTable[i].ts) < ALERT_COOLDOWN_MS) return true;
      dedupeTable[i].ts = now;
      return false;
    }
  }
  // Not found — insert into next slot
  strlcpy(dedupeTable[dedupeIdx].mac, macStr, 18);
  dedupeTable[dedupeIdx].ts = now;
  dedupeIdx = (dedupeIdx + 1) % DEDUPE_SLOTS;
  return false;
}

static void stopSniffing(const char* reason) {
  if (sniffingStopped) return;
  sniffingStopped = true;
  esp_wifi_set_promiscuous(false);
  dualPrintf("[flockyou] sniffing stopped: %s\n", reason);
}

static void applyInitialChannel() {
#if CHANNEL_MODE == CHANNEL_MODE_SINGLE
  currentChannel = SINGLE_CHANNEL;
#elif CHANNEL_MODE == CHANNEL_MODE_CUSTOM
  currentChannel = customChannels[0];
#else
  currentChannel = fullHopChannels[0];
#endif
  esp_wifi_set_channel(currentChannel, WIFI_SECOND_CHAN_NONE);
  lastHop = millis();  // start dwell timer precisely when channel is first set
}

static void updateChannelMode() {
  if (sniffingStopped) return;
#if CHANNEL_MODE == CHANNEL_MODE_SINGLE
  if (currentChannel != SINGLE_CHANNEL) {
    currentChannel = SINGLE_CHANNEL;
    esp_wifi_set_channel(currentChannel, WIFI_SECOND_CHAN_NONE);
  }
  return;
#else
  if (millis() - lastHop < CHANNEL_DWELL_MS) return;
  #if CHANNEL_MODE == CHANNEL_MODE_CUSTOM
    customChannelIndex = (customChannelIndex + 1) % customChannelCount;
    currentChannel = customChannels[customChannelIndex];
  #else
    fullHopIndex = (fullHopIndex + 1) % fullHopChannelCount;
    currentChannel = fullHopChannels[fullHopIndex];
  #endif
  esp_wifi_set_channel(currentChannel, WIFI_SECOND_CHAN_NONE);
  lastHop = millis();
#endif
}

static void printHeartbeat() {
  if (millis() - lastHeartbeat >= HEARTBEAT_MS) {
    dualPrintf("[flockyou] scanning (ch=%u mode=%s det=%d)\n",
                  currentChannel, channelModeName(), fyDetCount);
    lastHeartbeat = millis();
  }
}

// ============================================================
// DETECTION TABLE OPS
// ============================================================

static const char* alertTypeToMethod(AlertType t) {
  switch (t) {
    case ALERT_OUI_ADDR2:      return "oui_addr2";
    case ALERT_OUI_ADDR1:      return "oui_addr1";
    case ALERT_OUI_ADDR3:      return "oui_addr3";
    case ALERT_SSID:           return "ssid";
    case ALERT_WILDCARD_PROBE: return "wildcard_probe";
    default:                   return "unknown";
  }
}

// Returns index of entry (new or updated), or -1 if table is full.
// Returns index, and sets *outChirpWorthy = true when the caller should fire
// the ascending new-discovery chirp. Chirp-worthy means either (a) MAC is
// brand new to this session, or (b) MAC is known but hasn't been seen in
// REDISCOVER_MS — i.e. it left RF range and came back.
static int fyAddDetection(const char* mac, const char* method,
                          int8_t rssi, uint8_t ch, const char* ssid,
                          bool* outChirpWorthy) {
  uint32_t now = millis();
  for (int i = 0; i < fyDetCount; i++) {
    if (strcasecmp(fyDet[i].mac, mac) == 0) {
      bool rediscover = (now - fyDet[i].lastSeen) > REDISCOVER_MS;
      if (fyDet[i].count < 0xFFFF) fyDet[i].count++;
      fyDet[i].lastSeen = now;
      fyDet[i].rssi     = rssi;
      fyDet[i].channel  = ch;
      if (ssid && ssid[0] && !fyDet[i].ssid[0]) {
        strlcpy(fyDet[i].ssid, ssid, sizeof(fyDet[i].ssid));
      }
      fyDirty = true;
      if (outChirpWorthy) *outChirpWorthy = rediscover;
      return i;
    }
  }
  if (fyDetCount >= MAX_DETECTIONS) {
    if (outChirpWorthy) *outChirpWorthy = false;
    return -1;
  }
  FYDetection& d = fyDet[fyDetCount];
  strlcpy(d.mac,    mac,                       sizeof(d.mac));
  strlcpy(d.method, method ? method : "",      sizeof(d.method));
  d.rssi      = rssi;
  d.channel   = ch;
  d.firstSeen = now;
  d.lastSeen  = now;
  d.count     = 1;
  if (ssid && ssid[0]) strlcpy(d.ssid, ssid, sizeof(d.ssid));
  else                 d.ssid[0] = '\0';
  fyDetCount++;
  fyDirty = true;
  if (outChirpWorthy) *outChirpWorthy = true;
  return fyDetCount - 1;
}

// ============================================================
// JSON ESCAPE  — only needed for SSIDs (user-controlled bytes)
// ============================================================

static size_t jsonEscape(char* dst, size_t cap, const char* src) {
  size_t o = 0;
  if (cap == 0) return 0;
  for (size_t i = 0; src[i]; i++) {
    char c = src[i];
    if (c == '"' || c == '\\') {
      if (o + 2 >= cap) break;
      dst[o++] = '\\'; dst[o++] = c;
    } else if ((unsigned char)c < 0x20) {
      if (o + 6 >= cap) break;
      int n = snprintf(dst + o, cap - o, "\\u%04x", (unsigned)(unsigned char)c);
      if (n <= 0 || (size_t)n >= cap - o) break;
      o += (size_t)n;
    } else {
      if (o + 1 >= cap) break;
      dst[o++] = c;
    }
  }
  dst[o] = '\0';
  return o;
}

// ============================================================
// CRC32  (zlib / SPIFFS-tool compatible polynomial 0xEDB88320)
// ============================================================

static uint32_t fyCRC32Update(uint32_t crc, const uint8_t* data, size_t len) {
  crc = ~crc;
  for (size_t i = 0; i < len; i++) {
    crc ^= data[i];
    for (int k = 0; k < 8; k++)
      crc = (crc >> 1) ^ (0xEDB88320u & -(int32_t)(crc & 1));
  }
  return ~crc;
}
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
void loop() {
  updateChannelMode();
  drainAlertQueue();   // Serial.printf happens here, not in callback
  autosaveTick();      // periodic SPIFFS write if dirty
  heartbeatTick();     // audible beep-pair while a target is still in range
  ledTick();           // turn off LED after LED_FLASH_MS
  printHeartbeat();
  delay(1);
}

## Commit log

2026-06-03 feat: add M5Atom Echo/Lite, Atom VoiceS3R (ESP32-S3) board support
    Hardware support added
    - M5Atom Echo (USE_M5ATOM_ECHO): NeoPixel LED + GPIO25 buzzer
    - M5Atom Lite (USE_M5ATOM_LITE): NeoPixel LED, no buzzer
    - Atom VoiceS3R (USE_M5ATOM_VOICES3R): ESP32-S3-PICO-1-N8R8, ES8311
    I2S speaker via M5Unified, no RGB LED, button on GPIO41
    platformio.ini
    - [env:m5atom-echo]: Adafruit NeoPixel, usbserial port, 1.5Mbaud upload
    - [env:m5atom-lite]: same board, no buzzer flag
    - [env:m5atom-voices3r]: espressif32@6.7.0, esp32-s3-devkitc-1, qio_opi
    PSRAM, ARDUINO_USB_CDC_ON_BOOT, M5Unified@^0.2.2
    main.cpp
    - TESTING_MODE guarded with #ifndef so build flag can override it
    - Adafruit NeoPixel include gu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
    [partitions_4mb.csv]
2026-06-03 docs: add multi-board support table, per-board flash commands, testing mode docs
    - Restored [env:xiao_esp32s3] (Seeed XIAO ESP32-S3, original upstream board)
    - Added Supported Hardware table: xiao_esp32s3 / esp32dev / m5atom-echo /
    m5atom-lite / m5atom-voices3r with port types, audio/LED notes
    - Replaced generic 'pio run' section with board-specific flash + monitor
    commands for all five environments
    - Added VoiceS3R section: kill-port-holder one-liner + esptool fallback
    for ESP32-S3 native USB-CDC (fixes 'port busy' upload errors)
    - Added Testing mode section: -DTESTING_MODE=1 build flag instructions
    - Pin maps for XIAO ESP32-S3 (original) and Atom VoiceS3R
    - Removed flash_atom.sh and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
